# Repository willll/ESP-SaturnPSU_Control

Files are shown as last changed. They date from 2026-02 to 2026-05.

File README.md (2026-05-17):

# ESP8266 D1 HTTP Control

[YouTube Demo: ESP8266 D1 Control Device](https://www.youtube.com/watch?v=zFmUQA3u5PM)

This project runs on an ESP8266 NodeMCU (ESP-12E, CP2102) and exposes a web page plus a REST API to control the D1 pin (GPIO5).

**Vibe coded project for learning purpose only.**

## Hardware Features
- **D1 (GPIO5):** Relay control output (active HIGH)
- **D2 (GPIO4):** Physical NO push button for manual D1 toggle (debounced, respects latch period)
- **Optional:** 10kΩ pull-up resistor for D2 (use only if internal pull-up is insufficient)
- **Relay:** Omron G6B-1114P-US or compatible
- **See:** `hw/BOM_ESP8266_Relay_Control.txt` for full parts list

## Requirements
- PlatformIO (recommended)
- ESP8266 NodeMCU (ESP-12E)
- Python 3.8+ with pip

## Install PlatformIO CLI (Linux)

### Option A: pipx (isolated install, recommended)
1) Install pipx

```bash
python3 -m pip install --user pipx
```

2) Ensure your shell can find pipx

```bash
python3 -m pipx ensurepath
```

3) Install PlatformIO

```bash
pipx install platformio
```

4) Open a new terminal and verify

```bash
pio --version
```

### Option B: pip (user install)
If you prefer not to use pipx:

```bash
python3 -m pip install --user platformio
```

Then verify:

```bash
pio --version
```

### Option C: system packages
Some distros ship a PlatformIO package (may be older). If you use it, ensure `pio --version` shows a recent release.

## USB serial permissions (Linux)
If upload or monitor fails with permission errors, add your user to the serial group and re-login:

```bash
sudo usermod -a -G dialout "$USER"
```

After logging out and back in, confirm access:

```bash
groups
```

Typical device nodes for CP2102 are `/dev/ttyUSB0` or `/dev/ttyUSB1`.

## Regenerate venv and build tools
This project includes a small bootstrap script and `requirements.txt` to recreate the local Python virtual environment and prefetch PlatformIO build tools.

Files:
- `requirements.txt`: Python dependencies for the local venv (includes PlatformIO CLI)
- `scripts/bootstrap.sh`: Creates `.venv`, installs dependencies, and downloads PlatformIO packages

Clean start (optional):

```bash
rm -rf .venv .pio
```

If you also want to wipe globally cached PlatformIO packages (not required):

```bash
rm -rf ~/.platformio
```

Run the bootstrap script:

```bash
chmod +x scripts/bootstrap.sh
./scripts/bootstrap.sh
```

After bootstrap, build as usual:

```bash
./.venv/bin/pio run
```

## WiFi configuration
WiFi credentials are loaded from an unencrypted JSON file on LittleFS.

1. Copy data/wifi_replace_me.json to data/wifi.json
2. Edit data/wifi.json with your credentials
3. Upload the filesystem (see below)

### JSON schema
- `ssid` (string, required): WiFi network name
- `password` (string, required): WiFi password (can be empty for open networks)
- `hostname` (string, optional): Device hostname shown by the router
- `connect_timeout_ms` (number, optional): Max time to wait for WiFi connect; default is 20000
- `notes` (array of strings, optional): Any extra notes; ignored by firmware

Example (wifi_replace_me.json):

```json
{
	"ssid": "your-ssid",
	"password": "your-password",
	"hostname": "esp8266-d1",
	"connect_timeout_ms": 20000,
	"notes": [
		"Replace ssid/password with your network",
		"Extra fields are ignored by the firmware"
	]
}
```

Upload the filesystem before flashing the firmware:

```bash
pio run -t uploadfs
```

## mDNS (Multicast DNS) Support

The device automatically registers on your local network using mDNS, making it accessible via a friendly hostname instead of IP address.

### How to Access

**Web UI:**
```
http://<hostname>.local
```

**REST API:**
```
http://<hostname>.local/api/v1/status
```

**Example:** If your wifi.json has `"hostname": "saturnpsu"`, access it at:
```
http://saturnpsu.local
```

### Test mDNS Connectivity

From any device on the same network, ping the device to verify mDNS registration:

```bash
ping saturnpsu.local
```

**Expected output:**
```
64 bytes from 192.168.1.106: seq=0 ttl=255 time=2.230 ms
```

### mDNS Requirements

- Device and client must be on the **same WiFi network**
- Client device needs **mDNS support** (built-in on macOS, Linux, Windows 10+)
- Hostname must be set in `wifi.json` (see WiFi configuration section above)
- If hostname is empty, mDNS responder is disabled

### Hostname Configuration

Edit `data/wifi.json`:

```json
{
  "hostname": "saturnpsu"
}
```

After changing the hostname, re-upload the filesystem:

```bash
pio run -t uploadfs
```

Reboot the device or power cycle to apply.

## Build and upload

```bash
pio run -t upload
```

Open serial monitor at 74880 to see the device IP and boot logs:

```bash
pio device monitor -b 74880
```
If you are using VS Code tasks, run:
- PlatformIO: Monitor

## Web UI Features

Visit the device IP in a browser to open the control page. The web UI provides:

- **ON/OFF/TOGGLE Buttons:** Instantly control the D1 pin state. Button color reflects the current state (green for ON, red for OFF). Buttons are disabled while the latch is active or if the action is not allowed.
- **Latch Period Input:** Set the latch period (in seconds) to prevent rapid toggling. The input is for user entry only and is not auto-refreshed from device status. Allowed range: 1–3600 seconds.
- **Status Display:** Shows the current D1 state and latch period, updates in real time (every 200ms).
- **Debug Log:** Scrollable area below the controls displays recent debug messages, actions, and API errors. Auto-scrolls as new messages arrive.
- **No Refresh Button:** The UI auto-updates status and disables the Refresh button (removed in latest version).

### Example UI

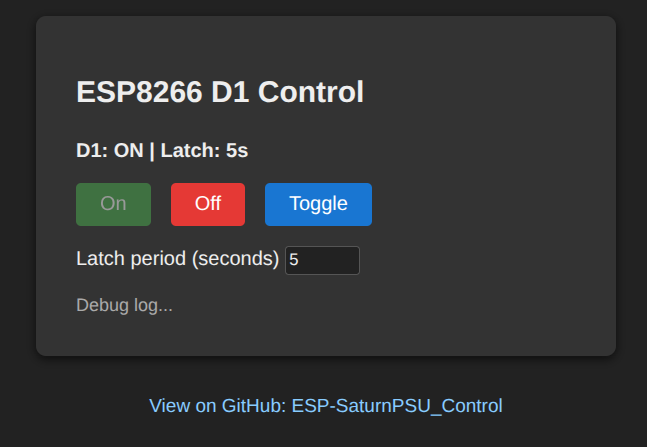
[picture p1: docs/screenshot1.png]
Web UI Screenshot 1

*Main control panel with ON/OFF/TOGGLE, latch input, and debug log.*

> **Tip:** If you see 'Status: ERROR' or debug messages about API failures, check your device connection and network.

## Physical Push Button (D2)

- **D2 (GPIO4):** Connect a normally open (NO) push button between D2 and GND.
- **Behavior:** Pressing the button toggles D1, subject to the latch period (cannot toggle if latch is active). Input is debounced in firmware.
- **Optional:** Add a 10kΩ pull-up resistor if needed (firmware uses INPUT_PULLUP).

## REST API

### REST API Endpoints

| Method | Path | Description | Status | Response |
|---|---|---|---|---|
| GET | / | Web UI (HTML page) | 200 | (HTML) |
| GET | /api/v1/status | Get current relay status and latch info | 200 | See example below |
| POST | /api/v1/on | Set D1 HIGH (ON), starts latch timer if set | 200/423 | `{ "relay_status": "ON", ... }` |
| POST | /api/v1/off | Set D1 LOW (OFF), starts latch timer if set | 200/423 | `{ "relay_status": "OFF", ... }` |
| POST | /api/v1/toggle | Toggle D1 state, starts latch timer if set | 200/423 | `{ "relay_status": "ON\|OFF", ... }` |
| GET | /api/v1/latch  | Get current latch period (seconds) | 200 | `{ "latch": 5 }` |
| POST | /api/v1/latch  | Set latch period (1-3600 seconds, constraints enforced) | 200/400 | `{ "latch": 10 }` |
| GET | /menu | Plain-text status menu (for legacy/CLI use) | 200 | (text) |
| POST | /api/v1/reset  | Clear latch, set D1 LOW (test setup/reset) | 200 | `{ "reset": true }` |
| GET | /openapi.yaml  | OpenAPI 3.0 specification of this API | 200 | (YAML) |

### Status Endpoint Response Format

```json
{
  "relay_status": "ON",
  "latch": 5,
  "latch_timer_active": false,
  "latch_timer_expiry": 0,
  "millis": 1234567
}
```

| Field | Type | Description |
|---|---|---|
| `relay_status` | string | Current relay state: `"ON"` or `"OFF"` |
| `latch` | number | Latch period in seconds (1–3600, or clamped) |
| `latch_timer_active` | boolean | True if latch is currently active and preventing changes |
| `latch_timer_expiry` | number | Milliseconds when latch expires (0 if not active) |
| `millis` | number | Device uptime in milliseconds (for sync reference) |

### HTTP Status Codes

| Code | Meaning | Example |
|---|---|---|
| **200** | Success | Any control or status request succeeded |
| **400** | Bad Request | Invalid JSON in POST body or missing required fields |
| **423** | Locked | Latch is active; state change blocked until latch expires |
| **404** | Not Found | Endpoint doesn't exist |
| **500** | Server Error | Firmware error (rare) |

### Usage Examples

#### Get Current Status
```bash
curl http://saturnpsu.local/api/v1/status
```

**Response:**
```json
{
  "relay_status": "OFF",
  "latch": 5,
  "latch_timer_active": false,
  "latch_timer_expiry": 0,
  "millis": 42325
}
```

#### Turn Relay ON
```bash
curl -X POST http://saturnpsu.local/api/v1/on
```

**Response (200):**
```json
{
  "relay_status": "ON",
  "latch": 5,
  "latch_timer_active": true,
  "latch_timer_expiry": 47325,
  "millis": 42325
}
```

**Response if latch active (423):**
```json
{
  "error": "Latch active"
}
```

#### Set Latch Period
```bash
curl -X POST http://saturnpsu.local/api/v1/latch \
  -H "Content-Type: application/json" \
  -d '{"latch": 10}'
```

**Response (200):**
```json
{
  "latch": 10
}
```

**Invalid constraints (auto-clamped to 1-3600):**
```bash
# Request: latch = 0 (below minimum)
curl -X POST http://saturnpsu.local/api/v1/latch \
  -H "Content-Type: application/json" \
  -d '{"latch": 0}'
# Response: {"latch": 1}  (clamped to min)

# Request: latch = 9999 (above maximum)
curl -X POST http://saturnpsu.local/api/v1/latch \
  -H "Content-Type: application/json" \
  -d '{"latch": 9999}'
# Response: {"latch": 3600}  (clamped to max)
```

#### Toggle Relay
```bash
curl -X POST http://saturnpsu.local/api/v1/toggle
```

#### Get Latch Period
```bash
curl http://saturnpsu.local/api/v1/latch
```

**Response:**
```json
{
  "latch": 5
}
```

#### Reset (Clear latch, set D1 LOW)
```bash
curl -X POST http://saturnpsu.local/api/v1/reset
```

**Response:**
```json
{
  "reset": true
}
```

### API Behavior Notes

- **Latch Constraints:** Latch period is automatically clamped to 1–3600 seconds. Values of 0 or below are set to 1; values above 3600 are set to 3600.
- **Latch Behavior:** When a control endpoint (on/off/toggle) executes successfully, a latch timer starts. Any subsequent control requests return **423 Locked** until the timer expires.
- **No Auto-Revert:** After the latch expires, the relay **remains in its set state** (does not auto-revert).
- **Idempotent:** All endpoints are safe to call repeatedly; duplicate requests are harmless.
- **mDNS Support:** Endpoints are accessible via `http://<hostname>.local/api/v1/...` on any client on the same network.

### OpenAPI Specification

Full OpenAPI 3.0 specification available at:
```
GET /openapi.yaml
```

Serve in [SwaggerUI](https://swagger.io/tools/swagger-ui/) or [ReDoc](https://redoc.ly/) for interactive exploration.

#### Details

- **/api/v1/on, /api/v1/off, /api/v1/toggle:** All return the new D1 state as JSON. If the latch is active, state changes are rejected with `{ "error": "Latch active" }` and HTTP 423.
- **/api/v1/latch:** GET returns current latch period; POST sets a new period (range: 1–3600 seconds). Returns new value as JSON. Setting to 0 disables the latch.
- **/api/v1/reset:** For test setup. Immediately disables latch and sets D1 LOW. Always returns `{ "reset": true }`.
- **/api/v1/status:** Returns current D1 state and latch timer (if active).
- **/menu:** Returns a plain-text status summary for CLI/legacy use.

##### Example: /api/v1/status
```json
{"relay_status":"ON", "latch":0}
```

##### Example: /api/v1/latch (POST)
Request:
```json
{"latch": 10}
```
Response:
```json
{"latch": 10}
```
*Note: Latch period must be between 1 and 3600 seconds. 0 disables latch. See SRS for details.*

##### Example: /api/v1/reset
Request:
```bash
curl -X POST http://<device-ip>/api/v1/reset
```
Response:
```json
{"reset":true}
```

## Automated Testing

This project includes automated and manual test suites for firmware, REST API, web UI, and hardware features:

- **Robot Framework API tests** (recommended, runs in Docker):
	- Location: `scripts/test_api.robot`
	- Run with Docker:
		```bash
		docker build -t esp8266-robot-tests .
		docker run --rm -e DEVICE_IP=192.168.1.107 esp8266-robot-tests
		```
		(Replace the IP as needed.)
	- See `scripts/robot_test_README.md` for details.

- **Python API test script** (optional):
	- Location: `scripts/test_api.py`
	- Run with:
		```bash
		python3 scripts/test_api.py 192.168.1.107
		```

- **Manual Hardware/UI Tests:**
	- See `docs/test-campaign.md` for a full checklist, including:
		- D2 push button toggles D1, respects latch period, and is debounced
		- UI disables ON/OFF/TOGGLE during latch
		- Latch input is input-only (not auto-refreshed)
		- No Refresh button (UI auto-updates)
		- All REST API and UI features

Test results are shown in the terminal or browser. The Robot Framework suite covers all REST API endpoints and device logic.

## Test Campaign

See `docs/test-campaign.md` for a full manual and automated test checklist covering:
- Firmware and REST API
- Web UI (including D2 push button and latch logic)
- Hardware wiring and deployment
- Documentation completeness

## Hardware Images

### Device Front View 1
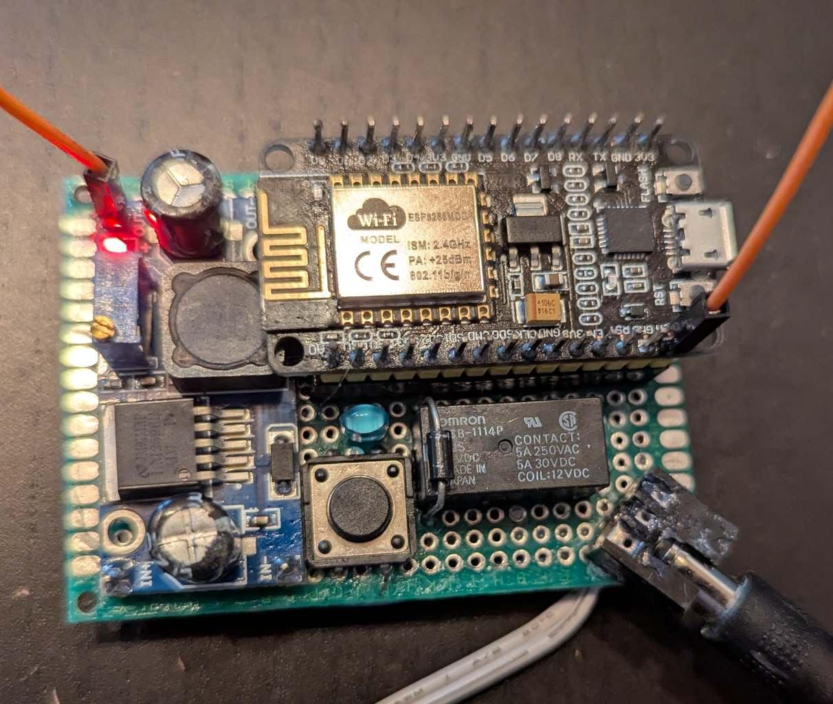
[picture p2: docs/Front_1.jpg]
Device Front 1


### Device Front View 2
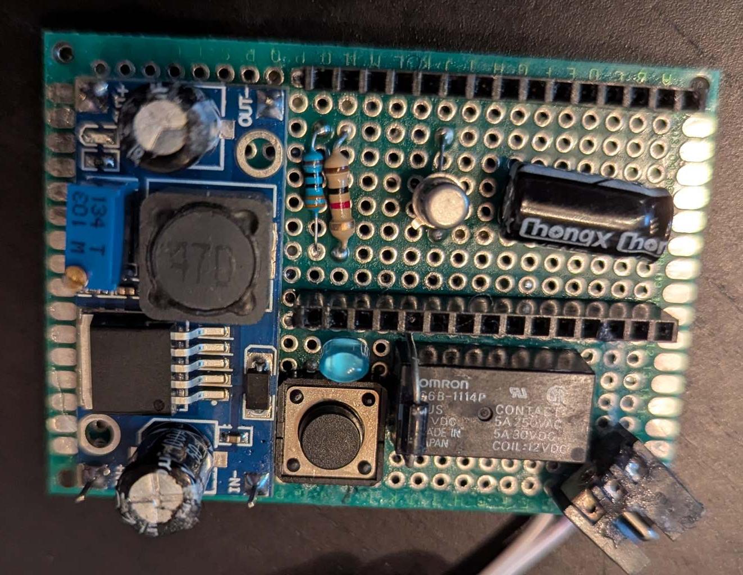
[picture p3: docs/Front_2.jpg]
Device Front 2


## Notes
- D1 corresponds to GPIO5 (relay control output)
- D2 corresponds to GPIO4 (NO push button input)
- The control output is active HIGH by default
- Latch period prevents rapid toggling; minimum 1s, maximum 3600s
- D2 input is debounced and respects latch lockout
- UI disables ON/OFF/TOGGLE during latch; latch input is not auto-refreshed
- See SRS and test campaign for full requirements

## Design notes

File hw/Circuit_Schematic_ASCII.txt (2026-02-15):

================================================================================
        ESP8266 NodeMCU to Omron G6B-1114P-US Relay Control Circuit
                         CIRCUIT SCHEMATIC DIAGRAM
================================================================================

                                    +12V DC POWER SUPPLY
                                        │
                                        │ +12V
                                        │
                   ┌────────────────────┴────────────────────┐
                   │                    │                     │
                   │                    │                   ──┴──  Cathode (−)
                   │                    │                   ╱   ╲  (Stripe)
                   │                    │                  │  D1 │ 1N4007
                   │                    │                   ╲   ╱  Flyback
                   │                    │                   ──┬──  Diode
                   │                    │                     │ Anode (+)
                   │                    │                     │
                   │             ┌──────┴──────┐              │
                   │             │             │              │
                   │             │   RELAY K1  │              │
                   │             │  G6B-1114P  │              │
                   │             │   -US 12V   │              │
                   │             │             │              │
                   │         (1) │●  COIL  ●│ (2)            │
                   │    Coil +   │             │  Coil −      │
                   └─────────────┤   ┌───┐     ├──────────────┘
                                 │   │ ~ │     │
                                 │   │ ~ │     │
                                 │   │ ~ │     │
                                 │   └───┘     │
                                 │             │
                                 │             │
                                 │ (3)     (4) │
                                 │  ●       ●  │
                                 └──┬───────┬──┘
                                    │       │
                                   COM      NO
                                    │       │
                                    │       │
                               (To Load Switching)

                   ┌─────────────────────────────────────────┐
                   │                                         │
                   │        ESP8266 NodeMCU                  │
                   │        ESP-12E CP2102                   │
                   │                                         │
                   │  ┌──────────────────────────┐           │
                   │  │                          │           │
    ┌──────────┐   │  │      ESP8266-12E         │           │
    │ USB 5V   ├───┤  │      WiFi Module         │           │
    │ Power    │   │  │                          │           │
    └──────────┘   │  └──────────────────────────┘           │
                   │                                         │
                   │                                         │
                   │  D1 (GPIO5) ●───────────┐               │
                   │                         │               │
                   │                         │               │
                   │  GND         ●──────────┼───────┐       │
                   │                         │       │       │
                   └─────────────────────────┼───────┼───────┘
                                             │       │
                                             │       │
                      3.3V Signal            │       │
                      (Control)              │       │
                                             │       │
                                         ┌───┴───┐   │
                                         │       │   │
                                         │  R1   │   │
                                         │ 1kΩ   │   │
                                         │       │   │
                                         └───┬───┘   │
                                             │       │
                                             │ Base  │
                                             ▼       │
                                           ┌─┴─┐     │
                                           │╱ ╲│     │
                                      C ───┤   ├     │  Q1: 2N2222
                                           │╲ ╱│     │  NPN Transistor
                                           └─┬─┘     │
                                             │       │
                                             │ Emitter
                                             ▼       │
                                             │       │
                                          ═══╧═══════╧═══  Common GND
                                            GND
                                             │
                                             │
                                          12V DC (−)

================================================================================
CONNECTION TABLE
================================================================================

FROM                    TO                      COMPONENT/WIRE
-------------------------------------------------------------------------------
12V Supply (+)    →     Relay Pin 1             Red Wire
12V Supply (+)    →     Diode D1 Cathode        Red Wire
12V Supply (−)    →     Common GND              Black Wire

Relay Pin 1       →     Relay Coil (+)          Internal
Relay Pin 2       →     Relay Coil (−)          Internal
Relay Pin 2       →     Transistor Q1 Collector Orange Wire
Relay Pin 2       →     Diode D1 Anode          Orange Wire

Transistor Q1:
  - Collector     →     Relay Pin 2             Orange Wire
  - Base          →     Resistor R1 Pin 2       Orange Wire
  - Emitter       →     Common GND              Black Wire

Resistor R1:
  - Pin 1         →     ESP8266 D1 (GPIO5)      Orange Wire
  - Pin 2         →     Transistor Q1 Base      Orange Wire

Diode D1:
  - Cathode (−)   →     +12V / Relay Pin 1      Red Wire
  - Anode (+)     →     Relay Pin 2 / Collector Orange Wire

ESP8266 NodeMCU:
  - D1 (GPIO5)    →     Resistor R1 Pin 1       Orange Wire
  - GND           →     Common GND              Black Wire
  - USB           →     5V Power Supply         USB Cable

Relay Contacts:
  - Pin 3 (COM)   →     Load Common             User Wire
  - Pin 4 (NO)    →     Load Switched Side      User Wire

================================================================================
SIGNAL FLOW
================================================================================

CONTROL SIGNAL PATH:
ESP8266 GPIO5 (3.3V) → R1 (1kΩ) → Q1 Base → Q1 Emitter → GND
Current: ~2.6mA

POWER SWITCHING PATH (when GPIO5 = HIGH):
+12V → Relay Coil Pin 1 → Relay Coil → Relay Coil Pin 2 → Q1 Collector → 
Q1 Emitter → GND
Current: ~30mA

PROTECTION PATH:
When relay de-energizes, flyback voltage: 
Relay Coil → D1 Anode → D1 Cathode → +12V (dissipates energy safely)

================================================================================
VOLTAGE AND CURRENT SPECIFICATIONS
================================================================================

Node                Voltage (V)     Current (mA)    Notes
-------------------------------------------------------------------------------
+12V Supply         12.0            30-50          Power for relay only
ESP8266 GPIO5       3.3             2.6            Control signal
Transistor Base     0.7             2.6            Forward biased
Transistor Emitter  0               32.6           To ground
Relay Coil +        12.0            30             When energized
Relay Coil −        0.2-0.5         30             VCE(sat) voltage
Common GND          0               32.6           Reference point

================================================================================
COMPONENT STRESS ANALYSIS
================================================================================

Component       Parameter           Operating   Maximum   Margin    Status
-------------------------------------------------------------------------------
Q1 (2N2222)    Collector Current     30mA       600mA     20x       ✓ SAFE
Q1 (2N2222)    Collector-Emitter V   12V        40V       3.3x      ✓ SAFE
Q1 (2N2222)    Base Current          2.6mA      -         -         ✓ SAFE
Q1 (2N2222)    Power Dissipation     ~10mW      500mW     50x       ✓ SAFE

R1 (1kΩ)       Power Dissipation     6.8mW      250mW     37x       ✓ SAFE
R1 (1kΩ)       Voltage               2.6V       -         -         ✓ SAFE

D1 (1N4007)    Forward Current       30mA       1A        33x       ✓ SAFE
D1 (1N4007)    Reverse Voltage       12V        1000V     83x       ✓ SAFE

K1 Relay       Coil Voltage          12V        13.2V max 1.1x      ✓ SAFE
K1 Relay       Coil Current          30mA       -         -         ✓ SAFE

ESP8266 GPIO   Output Current        2.6mA      12mA max  4.6x      ✓ SAFE

================================================================================
OPERATING MODES
================================================================================

MODE 1: RELAY OFF (GPIO5 = LOW or 0V)
--------------------------------------
- Transistor Q1 is OFF (not conducting)
- No current flows through relay coil
- Relay contacts: Pin 3 (COM) is OPEN (not connected to Pin 4)
- Load is OFF
- System power: ~80mA (ESP8266 only)

MODE 2: RELAY ON (GPIO5 = HIGH or 3.3V)
----------------------------------------
- Transistor Q1 is ON (saturated)
- Current flows: 12V → Relay Coil → Q1 → GND (~30mA)
- Relay contacts: Pin 3 (COM) is CLOSED to Pin 4 (NO)
- Load is ON (switched)
- System power: ~110mA (ESP8266 + relay)

MODE 3: RELAY SWITCHING OFF (GPIO5 transitions HIGH → LOW)
-----------------------------------------------------------
- Transistor Q1 turns OFF
- Relay coil collapses, generating back-EMF (flyback voltage)
- Diode D1 conducts, providing path for inductive current
- Energy dissipates through D1 and coil resistance
- Duration: ~5-10ms
- Without D1: Voltage spike could exceed 400V and destroy Q1!

================================================================================
DESIGN CALCULATIONS
================================================================================

BASE RESISTOR CALCULATION (R1):
--------------------------------
VCC (ESP8266) = 3.3V
VBE (Q1) = 0.7V
IB (desired) = 2-3mA (for IC = 30mA with hFE = 20, worst case)

R1 = (VCC - VBE) / IB
R1 = (3.3V - 0.7V) / 0.0026A
R1 = 2.6V / 0.0026A
R1 = 1000Ω = 1kΩ ✓

Actual IB = 2.6mA
With hFE = 100 (typical), IC(max) = 260mA (adequate for 30mA relay)

TRANSISTOR SATURATION CHECK:
-----------------------------
IC (relay) = V / R = 12V / 400Ω = 30mA
IB (actual) = 2.6mA
hFE (forced) = IC / IB = 30mA / 2.6mA = 11.5

Since forced hFE << typical hFE, transistor is fully saturated ✓
VCE(sat) ≈ 0.2-0.3V (collector voltage close to ground)

DIODE SELECTION:
----------------
Peak flyback voltage (without diode) = L × (dI/dt)
Estimated: 200-400V for typical relay

1N4007 specs:
- Reverse voltage: 1000V > 400V ✓
- Forward current: 1A > 30mA ✓
- Recovery time: 30µs (adequate for relay switching)

Selection: 1N4007 is appropriate and provides safety margin

POWER SUPPLY SIZING:
--------------------
Relay coil power = V × I = 12V × 30mA = 360mW
Safety factor = 2× (for inrush and reliability)
Minimum supply = 360mW × 2 = 720mW

Recommended: 12V @ 500mA (6W) provides adequate margin ✓

================================================================================
TROUBLESHOOTING GUIDE
================================================================================

PROBLEM: Relay doesn't click when GPIO5 goes HIGH
POSSIBLE CAUSES:
  1. No 12V supply connected → Check power supply
  2. Common ground not connected → Connect ESP8266 GND to 12V GND
  3. Wrong GPIO pin → Verify using D1 (GPIO5)
  4. Transistor damaged or wrong pinout → Check with multimeter
  5. Diode reversed → Cathode should be at +12V

PROBLEM: Relay clicks but contacts don't switch
POSSIBLE CAUSES:
  1. Wrong relay pins used for load → Use Pin 3 (COM) and Pin 4 (NO)
  2. Load current exceeds relay rating → Check load current vs 5A rating
  3. Relay contacts welded → Replace relay

PROBLEM: Transistor gets hot
POSSIBLE CAUSES:
  1. Transistor not saturating → Check base resistor value (1kΩ)
  2. Excessive collector current → Measure relay coil current
  3. Wrong transistor → Verify 2N2222 or equivalent

PROBLEM: ESP8266 resets when relay switches
POSSIBLE CAUSES:
  1. Power supply noise → Add 100µF capacitor across 12V supply
  2. Ground loop → Ensure single-point ground connection
  3. ESP8266 power supply inadequate → Use 1A USB supply

PROBLEM: Relay stays on permanently
POSSIBLE CAUSES:
  1. Transistor shorted → Replace transistor
  2. GPIO pin stuck HIGH → Check ESP8266 code
  3. Base resistor open → Check R1 connection

================================================================================
CIRCUIT ENHANCEMENTS (Optional)
================================================================================

1. LED INDICATOR
   Add LED + 470Ω resistor in series with relay coil to indicate state

2. MANUAL OVERRIDE
   Add push button in parallel with transistor C-E for manual testing

3. SNUBBER CIRCUIT
   Add RC snubber (0.1µF + 100Ω) across relay contacts for AC loads

4. MULTIPLE RELAYS
   Duplicate Q1/R1/D1/K1 circuit for each additional relay
   Use different GPIO pins (D2, D3, etc.)

5. OPTOCOUPLER ISOLATION
   Add 4N35 optocoupler between ESP8266 and transistor for galvanic isolation

6. POWER SUPPLY INTEGRATION
   Use LM7805 or buck converter to power ESP8266 from 12V supply

================================================================================
PCB LAYOUT RECOMMENDATIONS
================================================================================

1. Keep high-current paths (12V and relay) short and wide
2. Place flyback diode physically close to relay coil
3. Use ground plane for common GND
4. Separate analog and digital grounds if using ADC
5. Add mounting holes for relay and ESP8266
6. Include test points for troubleshooting
7. Label all connections on silkscreen
8. Use terminal blocks for external connections

================================================================================
END OF SCHEMATIC DIAGRAM
================================================================================

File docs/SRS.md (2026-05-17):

- The ON button shall be disabled when D1 is ON, and enabled otherwise.
- The OFF button shall be disabled when D1 is OFF, and enabled otherwise.
## Latch Functionality Requirement

- The latch period is a lockout interval that prevents frequent state changes. When a state change (ON, OFF, TOGGLE) occurs, further changes are blocked for the latch period. After the latch period expires, the relay state remains as set; it does not auto-revert. The latch period can be disabled by setting it to 0 (no lockout). The minimum allowed value for the latch (if enabled) is 1 second. Any attempt to set the latch to a negative value or above the maximum must be rejected.
# Software Requirements Specification (SRS)

## Project: ESP-SaturnPSU_Control

### 1. Introduction
#### 1.1 Purpose
This document specifies the requirements for the ESP-SaturnPSU_Control project, which provides firmware and a web-based user interface for controlling a relay (D1) on an ESP8266-based power supply unit, including REST API access, web UI, and automation support.

#### 1.2 Scope
- Control and monitor the D1 relay via web UI and REST API
- Configure latch timing for relay
- Provide feedback and debug information to the user
- Support automated build, upload, and test workflows

#### 1.3 Definitions
- **D1**: The relay control pin on the ESP8266
- **Latch**: The period (in seconds) during which the D1 status cannot be changed after activation
- **REST API**: HTTP endpoints for remote control
- **Web UI**: Browser-based interface served from the device

### 1.4 Constraints
- The default latch period shall be 5 seconds.
- The minimum latch period shall be 1 second.
- The maximum latch period shall be 3600 seconds (1 hour).
- Latch period values outside this range shall be rejected by the system.
- The system shall initialize with the default latch period on first boot or after a reset.

### 1.5 UI Constraints
- The web UI shall be responsive and usable on both desktop and mobile devices.
- All interactive elements (buttons, inputs) shall be clearly labeled and accessible.
- The ON button shall be green if D1 is 1 (ON), and red otherwise.
- The OFF button shall be red if D1 is 1 (ON), and green otherwise.
- The TOGGLE button shall always be blue.
- When the latch is active, the ON, OFF, and TOGGLE buttons shall be disabled.
- The status refresh interval shall be every 200 milliseconds.
- The debug log shall always be visible and update in real time.
- The latch period input is for input only and shall restrict values to the allowed range (1–3600 seconds). The value is not auto-refreshed from device status.
- The UI shall provide clear feedback for all user actions and errors.
- The UI shall include a link to the project’s GitHub repository in the footer.
- The UI shall not require any external resources at runtime (self-contained).
### 1.6 Network Requirements
- The system shall support mDNS (multicast DNS) to register the device on the local network.
- The device shall register with the hostname specified in `wifi.json`.
- The device shall be accessible via `<hostname>.local` from any client on the same WiFi network.
- If hostname is not set or is empty, the mDNS responder shall be disabled.
### 2. Overall Description
#### 2.1 Product Perspective
- Runs on ESP8266 NodeMCU hardware
- Uses PlatformIO for build and deployment
- Web UI is served from LittleFS
- REST API provides programmatic access

#### 2.2 Product Functions
- Turn D1 ON, OFF, or TOGGLE
- Toggle D1 using D2 push button (NO, debounced, respects latch period)
- Set latch period
- Display current D1 and latch status
- Show debug log in UI
- Visual feedback for D1 state in UI
- Automated build/upload/monitor script

#### 2.3 User Classes
- End User: Controls relay via web UI
- Integrator: Uses REST API for automation
- Developer: Builds, uploads, and tests firmware

#### 2.4 Operating Environment
- ESP8266 NodeMCU
- Modern web browser
- PlatformIO toolchain

### 3. Specific Requirements
#### 3.1 Functional Requirements
- [FR1] The system shall provide a web UI to control D1 (ON/OFF/TOGGLE)
- [FR2] The system shall provide a REST API for D1 control and status
- [FR3] The system shall allow setting the latch period via UI and API
- [FR4] The UI shall display the current D1 state and latch period
- [FR5] The UI shall visually highlight the ON/OFF button matching D1 state
- [FR6] The UI shall show a debug log of recent actions
- [FR7] The UI shall poll the backend for status updates every 200 milliseconds
- [FR8] The system shall provide a link to the GitHub project in the UI footer
- [FR9] The system shall support automated build, upload, and monitor via script
- [FR10] The system shall support toggling D1 via a physical D2 push button, respecting latch period and debouncing input.

#### 3.2 Non-Functional Requirements
- [NFR1] The UI shall be responsive and mobile-friendly
- [NFR2] The system shall handle API errors gracefully and inform the user
- [NFR3] The firmware and UI shall be self-contained and require no external dependencies at runtime
- [NFR4] The system shall be open source and documented
- [NFR5] The system shall support mDNS for network discovery via `<hostname>.local`
- [NFR6] The device shall be accessible without knowing its IPv4 address when on the same network

### 4. External Interface Requirements
#### 4.1 Hardware Interfaces
- ESP8266 NodeMCU with relay on D1

#### 4.2 Software Interfaces
- REST API endpoints: /api/v1/on, /api/v1/off, /api/v1/toggle, /api/v1/status, /api/v1/latch, /api/v1/reset
- Web UI: index.html served from LittleFS

#### 4.3 Communications Interfaces
- HTTP over WiFi

### 5. Other Requirements
- The project repository shall include documentation and automation scripts
- The system shall be validated using automated tests

---
End of SRS

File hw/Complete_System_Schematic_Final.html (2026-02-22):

# Complete ESP8266 Relay Control System - Final Schematic

Single 12V Power Supply | Manual Button | Status LED | WiFi Control Ready

⬇ Download Complete Schematic (SVG)

### 🎉 Complete System Features

- Single 12V Power Supply: Powers everything - no USB needed!
- Efficient Power Conversion: LM2596 buck converter (92% efficient, stays cool)
- Manual Control: Push button for local control (toggle function)
- Visual Feedback: Red LED shows when relay is ON
- WiFi Ready: ESP8266 can control via MQTT, HTTP, or home automation
- Protected Circuit: Flyback diode protects transistor from voltage spikes
- Professional Design: All components properly rated and specified

### 📝 Quick Reference

- Power Input: 12V DC, 500mA minimum (recommended 1A)
- ESP8266 Power: 5V regulated from LM2596
- Relay Control: D1 (GPIO5) controls via 2N2222A transistor
- Button Input: D2 (GPIO4) with internal pull-up
- Status LED: D3 (GPIO0) mirrors relay state
- Load Capacity: 5A @ 250VAC or 5A @ 30VDC

### ⚡ Power Consumption

- ESP8266 Idle: ~80mA @ 5V = 0.4W
- ESP8266 Active (WiFi): ~200mA @ 5V = 1.0W
- Relay Coil: ~30mA @ 12V = 0.36W
- Status LED: ~10mA @ 3.3V = 0.03W
- Total System: ~350mA @ 12V = 4.2W maximum

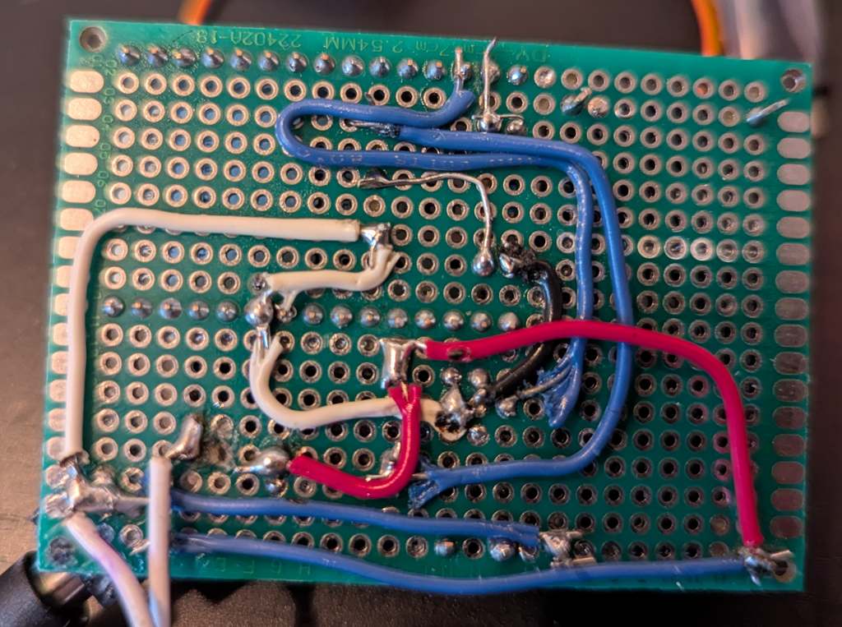
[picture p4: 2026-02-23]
docs/Back.jpg

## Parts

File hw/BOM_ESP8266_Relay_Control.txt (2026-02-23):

===================================================================================
                    BILL OF MATERIALS (BOM)
        ESP8266 NodeMCU to Omron G6B-1114P-US Relay Control Circuit
===================================================================================

Project: ESP8266 12VDC Relay Control
Date: February 15, 2024
Revision: 1.0

===================================================================================
COMPONENT LIST
===================================================================================

Item | Qty | Reference | Value/Part Number      | Description                        | Footprint/Package | Notes
-----|-----|-----------|------------------------|------------------------------------|--------------------|------------------------
  1  |  1  | U1        | ESP8266 NodeMCU        | ESP8266 ESP-12E Development Board  | NodeMCU Board      | CP2102 USB-UART
  2  |  1  | Q1        | 2N2222                 | NPN Transistor 600mA 40V           | TO-92              | Alt: BC547, 2N3904
  3  |  1  | R1        | 1kΩ                    | Resistor 1/4W 5%                   | Axial              | Carbon Film
  4  |  1  | D1        | 1N4007                 | Rectifier Diode 1A 1000V           | DO-41              | Alt: 1N4001-1N4007
  5  |  1  | K1        | G6B-1114P-US           | Relay SPST-NO 12VDC 5A             | PCB Mount 4-pin    | Omron
  6  |  1  | PS1       | 12V DC Supply          | 12V DC Power Supply 500mA min      | Barrel Jack/Term   | Wall Adapter
  7  |  1  | USB1      | USB Cable              | USB Micro-B Cable                  | Cable              | For ESP8266 power
  8  | AR  | WIRE      | 22 AWG Wire            | Stranded hookup wire               | Various colors     | Red, Black, Orange
  9  |  1  | SW1       | NO Push Button           | Momentary Push Button (Normally Open) | Panel/PCB Mount      | For D2 (GPIO4) user input
 10  |  0/1| R2        | 10kΩ (optional)          | Resistor 1/4W 5% (pull-up, if needed) | Axial                | Use if ESP8266 internal pull-up is insufficient

===================================================================================
DETAILED SPECIFICATIONS
===================================================================================

U1 - ESP8266 NodeMCU ESP-12E CP2102
------------------------------------
Manufacturer: Espressif Systems
Microcontroller: ESP8266 ESP-12E
USB-UART Bridge: CP2102
Operating Voltage: 3.3V (5V via USB)
GPIO Pins: 11 usable
Flash Memory: 4MB
Wi-Fi: 802.11 b/g/n
Current Draw: ~80mA (typical), 170mA (peak)
Dimensions: 58mm x 31mm x 13mm

Pinout Used:
  - D1 (GPIO5): Relay control signal output
  - D2 (GPIO4): NO push button input (user control)
  - GND: Ground reference
  - VIN/USB: 5V power input

Power Requirements: 5V 500mA via USB Micro-B

Q1 - 2N2222 NPN Transistor
---------------------------
Type: NPN Bipolar Junction Transistor
Package: TO-92
Collector Current (IC max): 600mA (800mA peak)
Collector-Emitter Voltage (VCEO): 40V
Power Dissipation: 500mW
DC Current Gain (hFE): 100-300 typical
Transition Frequency: 250 MHz

Pin Configuration (TO-92):
  Pin 1: Emitter (E)
  Pin 2: Base (B)
  Pin 3: Collector (C)

NOTE: Pin order may vary by manufacturer. Verify with datasheet!

Alternative Parts:
  - BC547 (100mA, more common in EU)
  - 2N3904 (200mA, common in US)
  - PN2222 (600mA, plastic package)
  - BC337 (800mA, higher current)

R1 - 1kΩ Resistor
------------------
Resistance: 1000Ω (1kΩ)
Power Rating: 1/4W (0.25W)
Tolerance: ±5% (or better)
Type: Carbon Film or Metal Film
Package: Axial Lead
Color Code: Brown-Black-Red-Gold

Purpose: Base current limiting resistor
Calculated Base Current: (3.3V - 0.7V) / 1000Ω ≈ 2.6mA
Actual Power: ~6.8mW (well within rating)

D1 - 1N4007 Rectifier Diode
----------------------------
Type: Rectifier Diode
Forward Current: 1A continuous
Reverse Voltage: 1000V
Forward Voltage Drop: 0.7V @ 1A
Package: DO-41 (Axial)
Recovery Time: 30µs

Polarity Marking: Cathode marked with stripe/band

Purpose: Flyback/Freewheeling diode
Function: Protects transistor from inductive kickback when relay de-energizes
Connection: Cathode to +12V (relay coil +), Anode to collector

Alternative Parts (in order of preference):
  - 1N4007 (1000V) - Recommended
  - 1N4004 (400V) - Adequate
  - 1N4001 (50V) - Minimum acceptable
  - UF4007 (1000V, fast recovery) - Best choice

K1 - Omron G6B-1114P-US Relay
-------------------------------
Manufacturer: Omron Electronics
Part Number: G6B-1114P-US
Type: Single Pole Single Throw - Normally Open (SPST-NO)
Package: PCB Mount, 4-pin through-hole
Mounting: Straight pins, 5mm pitch

Coil Specifications:
  - Nominal Voltage: 12VDC
  - Coil Resistance: 400Ω (typical)
  - Coil Current: 30mA (nominal)
  - Pick-up Voltage: 75% of nominal (9V)
  - Drop-out Voltage: 10% of nominal (1.2V)
  - Operate Time: 10ms max
  - Release Time: 5ms max

Contact Specifications:
  - Configuration: SPST-NO (Form A)
  - Contact Rating: 5A @ 250VAC, 5A @ 30VDC
  - Max Switching Voltage: 250VAC / 110VDC
  - Max Switching Current: 5A
  - Max Switching Power: 1250VA / 150W
  - Contact Resistance: 100mΩ max
  - Mechanical Life: 10,000,000 operations
  - Electrical Life: 100,000 operations (resistive load)

Pin Configuration (4-pin):
  Pin 1: Coil (+) - Connect to +12V
  Pin 2: Coil (-) - Connect to transistor collector
  Pin 3: COM (Common) - Load common terminal
  Pin 4: NO (Normally Open) - Load switched terminal

Dimensions: 29mm x 12.7mm x 15.5mm
Weight: Approximately 5g

Safety: UL, CSA, TÜV approved
Operating Temperature: -40°C to +85°C

PS1 - 12V DC Power Supply
--------------------------
Output Voltage: 12VDC ±5%
Output Current: 500mA minimum (1A recommended)
Input Voltage: 100-240VAC 50/60Hz (universal input)
Connector: 2.1mm or 2.5mm barrel jack, or terminal block
Regulation: <5% typical
Ripple: <100mV p-p typical
Protection: Overcurrent, overvoltage, short-circuit

Power Calculation:
  Relay Coil: 12V × 30mA = 360mW
  Safety Factor: 2x
  Recommended: 12V @ 500mA (6W) minimum

Note: This supply is ONLY for the relay circuit.
ESP8266 is powered separately via USB (5V).

USB1 - USB Cable for ESP8266
-----------------------------
Type: USB Type-A to Micro-B
Length: 1m typical (adjust as needed)
Purpose: Power and programming for ESP8266
Current Rating: 500mA minimum (1A recommended)

WIRE - Hookup Wire
------------------
Type: Stranded copper hookup wire
Gauge: 22 AWG (0.33 mm²)
Insulation: PVC
Voltage Rating: 300V minimum
Temperature Rating: 80°C minimum

Wire Lengths (approximate):
  - Red (+12V): 30cm
  - Black (GND): 50cm
  - Orange (Signal): 20cm

Color Coding:
  - Red: +12V power
  - Black: Ground (GND)
  - Orange/Yellow: Signal (GPIO)

===================================================================================
TOOLS REQUIRED
===================================================================================

- Soldering iron (25-40W)
- Solder (60/40 or lead-free)
- Wire strippers
- Needle-nose pliers
- Multimeter (for testing)
- Breadboard (optional, for prototyping)
- Jumper wires (optional)
- Helping hands or PCB holder

===================================================================================
ASSEMBLY NOTES
===================================================================================

1. VERIFY TRANSISTOR PINOUT
   - TO-92 pinout varies by manufacturer
   - Confirm with datasheet before soldering
   - Flat side typically indicates orientation

2. DIODE POLARITY
   - Cathode (stripe) MUST connect to +12V side
   - Incorrect orientation will damage transistor

3. COMMON GROUND
   - ESP8266 GND and 12V supply GND MUST be connected
   - This is critical for proper operation

4. POWER ISOLATION
   - ESP8266 powered via USB (5V)
   - 12V supply only for relay circuit
   - DO NOT connect 12V to ESP8266 VIN

5. RELAY CONTACT WIRING
   - Pin 3 (COM) and Pin 4 (NO) switch your load
   - Observe load voltage/current ratings
   - Use appropriate wire gauge for load current

6. D2 PUSH BUTTON WIRING
   - Connect one side of SW1 to D2 (GPIO4), other side to GND
   - Enable ESP8266 internal pull-up in firmware (INPUT_PULLUP)
   - If unreliable, add external 10kΩ pull-up resistor from D2 to 3.3V

===================================================================================
TESTING PROCEDURE
===================================================================================

1. Before applying power:
   - Verify all connections with multimeter
   - Check for shorts between power and ground
   - Verify transistor pinout
   - Confirm diode polarity

2. Initial power-up:
   - Connect ESP8266 USB only (no 12V yet)
   - Upload test sketch
   - Verify GPIO output with multimeter

3. Full circuit test:
   - Connect 12V supply
   - Run test program
   - Listen for relay click
   - Measure relay coil voltage
   - Test contact switching with multimeter

4. Load testing:
   - Start with low-current resistive load
   - Gradually increase to rated current
   - Monitor for overheating
   - Verify switching reliability

===================================================================================
ESTIMATED COSTS (USD, 2024)
===================================================================================

ESP8266 NodeMCU:          $4.00 - $8.00
2N2222 Transistor:        $0.10 - $0.30
1kΩ Resistor:            $0.05 - $0.10
1N4007 Diode:            $0.05 - $0.15
Omron G6B-1114P-US:       $3.00 - $6.00
12V Power Supply:         $5.00 - $10.00
USB Cable:                $2.00 - $5.00
Miscellaneous Wire:       $2.00 - $5.00

TOTAL ESTIMATED COST:     $16.20 - $34.55

Note: Prices vary by supplier and quantity
Bulk purchases significantly reduce per-unit cost

===================================================================================
SUPPLIERS
===================================================================================

General Electronics:
  - Digi-Key (www.digikey.com)
  - Mouser (www.mouser.com)
  - Newark/Element14 (www.newark.com)
  - Arrow Electronics (www.arrow.com)

Cost-Effective Options:
  - AliExpress (www.aliexpress.com) - Longer shipping
  - Amazon - Fast shipping, higher prices
  - eBay - Various sellers

Local:
  - Electronics specialty stores
  - Maker spaces
  - University surplus stores

===================================================================================
SAFETY WARNINGS
===================================================================================

⚠️ ELECTRICAL SAFETY
  - Disconnect all power before handling circuit
  - Use proper insulation on exposed connections
  - Observe relay contact voltage/current ratings
  - Do not exceed component specifications

⚠️ RELAY CONTACTS
  - Relay contacts are NOT isolated from coil
  - Switching AC mains requires proper safety measures
  - Use appropriate enclosure for high-voltage loads
  - Follow local electrical codes

⚠️ HEAT MANAGEMENT
  - Transistor may heat up under continuous operation
  - Ensure adequate ventilation
  - Consider heatsink if necessary

===================================================================================
REVISION HISTORY
===================================================================================

Rev 1.0 - 2024-02-15 - Initial release

===================================================================================
END OF BILL OF MATERIALS
===================================================================================

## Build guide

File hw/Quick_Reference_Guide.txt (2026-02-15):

╔══════════════════════════════════════════════════════════════════════════════╗
║                           QUICK REFERENCE GUIDE                              ║
║          ESP8266 NodeMCU to Omron G6B-1114P-US Relay Control Circuit         ║
╚══════════════════════════════════════════════════════════════════════════════╝

┌──────────────────────────────────────────────────────────────────────────────┐
│ COMPONENT PINOUT QUICK REFERENCE                                             │
└──────────────────────────────────────────────────────────────────────────────┘

┌─────────────────────────────────┐
│  2N2222 NPN TRANSISTOR (TO-92)  │
│                                 │
│    Flat Side                    │
│   ┌─────────┐                   │
│   │  E B C  │  (Looking at face)│
│   │  │ │ │  │                   │
│   └──┼─┼─┼──┘                   │
│      │ │ │                      │
│      1 2 3                      │
│                                 │
│  Pin 1: Emitter (E) → GND       │
│  Pin 2: Base (B) → R1           │
│  Pin 3: Collector (C) → Relay   │
│                                 │
│  ⚠️  VERIFY WITH YOUR DATASHEET │
│      Pin order varies!          │
└─────────────────────────────────┘

┌─────────────────────────────────┐
│  1N4007 DIODE                   │
│                                 │
│   ┌────────────┐                │
│───┤            ├───             │
│   └────────────┘                │
│        ▲                        │
│        │                        │
│     Cathode                     │
│     (Stripe)                    │
│                                 │
│  Cathode (−) → +12V             │
│  Anode (+)   → Collector        │
└─────────────────────────────────┘

┌─────────────────────────────────┐
│  OMRON G6B-1114P-US RELAY       │
│  (4-Pin Configuration)          │
│                                 │
│    Physical Pins (Bottom View)  │
│     ┌───────────────┐           │
│     │               │           │
│     │  ┌─────────┐  │           │
│     │  │ RELAY   │  │           │
│     │  └─────────┘  │           │
│     │               │           │
│     └───┬─┬───┬─┬───┘           │
│         │ │   │ │               │
│         1 2   3 4               │
│                                 │
│  Pin 1: Coil (+)  → +12V        │
│  Pin 2: Coil (−)  → Collector   │
│  Pin 3: COM       → Load common │
│  Pin 4: NO        → Load switch │
└─────────────────────────────────┘

┌──────────────────────────────────────────────────────────────────────────────┐
│ WIRING COLOR CODE                                                            │
└──────────────────────────────────────────────────────────────────────────────┘

🔴 RED    = +12V Power (to Relay Pin 1 and Diode Cathode)
⚫ BLACK  = Ground (Common GND - MUST connect ESP8266 and 12V supply)
🟠 ORANGE = Signal/Control (ESP8266 D1 → R1 → Transistor Base)
🟡 YELLOW = Collector path (Relay Pin 2 ← Transistor Collector)

┌──────────────────────────────────────────────────────────────────────────────┐
│ CONNECTION CHECKLIST                                                         │
└──────────────────────────────────────────────────────────────────────────────┘

Before Powering Up:

☐ 1. ESP8266 D1 (GPIO5) → 1kΩ Resistor → Transistor BASE
☐ 2. ESP8266 GND → Common Ground Point
☐ 3. Transistor EMITTER → Common Ground Point
☐ 4. Transistor COLLECTOR → Relay Pin 2 (Coil −)
☐ 5. +12V Supply → Relay Pin 1 (Coil +)
☐ 6. +12V Supply → Diode CATHODE (stripe end)
☐ 7. Diode ANODE → Relay Pin 2 / Collector junction
☐ 8. 12V Supply GND → Common Ground Point
☐ 9. Verify transistor pinout with multimeter
☐ 10. Double-check diode polarity (stripe to +12V)

┌──────────────────────────────────────────────────────────────────────────────┐
│ TESTING PROCEDURE                                                            │
└──────────────────────────────────────────────────────────────────────────────┘

Step 1: Visual Inspection
  ☐ All connections secure
  ☐ No shorts between power and ground
  ☐ Diode stripe pointing to +12V
  ☐ Transistor correctly oriented

Step 2: Resistance Check (Power OFF)
  ☐ Measure relay coil: Should read ~400Ω between pins 1 & 2
  ☐ Check for shorts: +12V to GND should be >10kΩ
  ☐ Verify ground continuity: ESP GND to 12V GND = 0Ω

Step 3: Power ESP8266 Only (No 12V yet)
  ☐ Connect USB to ESP8266
  ☐ Upload test code
  ☐ Measure GPIO5: Should toggle between 0V and 3.3V
  ☐ Measure at transistor base: Should see ~0.6-0.7V when GPIO HIGH

Step 4: Full Circuit Test
  ☐ Connect 12V supply
  ☐ Run test program
  ☐ Listen for relay "click"
  ☐ Measure relay coil voltage: Should be ~12V when activated
  ☐ Measure collector voltage: Should be near 0V when ON, 12V when OFF

Step 5: Load Test
  ☐ Connect low-current LED + resistor to relay contacts (test load)
  ☐ Verify switching action
  ☐ Test with actual load (within relay ratings)

┌──────────────────────────────────────────────────────────────────────────────┐
│ SAMPLE ARDUINO CODE                                                          │
└──────────────────────────────────────────────────────────────────────────────┘

// ESP8266 Relay Control - Basic Example
const int RELAY_PIN = D1;  // GPIO5

void setup() {
  pinMode(RELAY_PIN, OUTPUT);
  digitalWrite(RELAY_PIN, LOW);  // Relay OFF
  Serial.begin(115200);
  Serial.println("ESP8266 Relay Control Ready");
}

void loop() {
  // Turn relay ON
  digitalWrite(RELAY_PIN, HIGH);
  Serial.println("Relay ON");
  delay(2000);
  
  // Turn relay OFF
  digitalWrite(RELAY_PIN, LOW);
  Serial.println("Relay OFF");
  delay(2000);
}

// Advanced: Control via WiFi
#include <ESP8266WiFi.h>
#include <ESP8266WebServer.h>

const char* ssid = "YOUR_WIFI_SSID";
const char* password = "YOUR_WIFI_PASSWORD";

ESP8266WebServer server(80);

void setup() {
  pinMode(RELAY_PIN, OUTPUT);
  digitalWrite(RELAY_PIN, LOW);
  
  WiFi.begin(ssid, password);
  while (WiFi.status() != WL_CONNECTED) {
    delay(500);
  }
  
  server.on("/on", []() {
    digitalWrite(RELAY_PIN, HIGH);
    server.send(200, "text/plain", "Relay ON");
  });
  
  server.on("/off", []() {
    digitalWrite(RELAY_PIN, LOW);
    server.send(200, "text/plain", "Relay OFF");
  });
  
  server.begin();
  Serial.println("Server started at: " + WiFi.localIP().toString());
}

void loop() {
  server.handleClient();
}

┌──────────────────────────────────────────────────────────────────────────────┐
│ TROUBLESHOOTING QUICK FIXES                                                  │
└──────────────────────────────────────────────────────────────────────────────┘

Problem: Relay doesn't click
├─ Check: Is 12V supply connected and powered?
├─ Check: Is common ground connected? (MOST COMMON ISSUE)
├─ Measure: Voltage at transistor base when GPIO HIGH (should be ~0.7V)
└─ Measure: Voltage at relay coil Pin 1 (should be 12V)

Problem: Relay clicks but load doesn't switch
├─ Verify: Load connected to Pins 3 (COM) and 4 (NO)?
├─ Check: Load current within 5A rating?
└─ Test: Measure continuity between Pin 3 and 4 when relay activated

Problem: ESP8266 resets when relay switches
├─ Add: 100µF capacitor across 12V supply (near relay)
├─ Check: USB power supply adequate? (Use 1A minimum)
└─ Verify: Ground connections solid and short

Problem: Transistor gets hot
├─ Check: Base resistor is 1kΩ (not higher value)
├─ Measure: Collector current (should be ~30mA)
└─ Verify: Correct transistor (2N2222 or equivalent)

Problem: Diode gets hot
├─ CRITICAL: Check diode polarity immediately!
├─ Stripe (cathode) MUST be at +12V side
└─ If reversed, replace diode before continuing

┌──────────────────────────────────────────────────────────────────────────────┐
│ SAFETY REMINDERS                                                             │
└──────────────────────────────────────────────────────────────────────────────┘

⚠️  NEVER connect 12V to ESP8266 VIN or any GPIO pin
⚠️  ALWAYS connect common ground between ESP8266 and 12V supply
⚠️  VERIFY transistor pinout before soldering (varies by manufacturer)
⚠️  CHECK diode polarity (stripe to +12V)
⚠️  OBSERVE relay contact ratings (5A max)
⚠️  USE proper enclosure for AC mains loads
⚠️  DISCONNECT power before handling circuit

┌──────────────────────────────────────────────────────────────────────────────┐
│ MEASUREMENT REFERENCE VALUES                                                 │
└──────────────────────────────────────────────────────────────────────────────┘

Location                Expected Voltage    Expected Current    Notes
─────────────────────────────────────────────────────────────────────────────
ESP8266 GPIO5 (HIGH)    3.3V               2-3mA output        Control signal
Transistor Base         0.6-0.7V           2.6mA               When ON
Transistor Collector    0.2-0.5V (ON)      30mA                When saturated
                        12V (OFF)          0mA                 When cutoff
Relay Coil Pin 1        12V                30mA                When activated
Relay Coil Pin 2        0.2-0.5V           30mA                When activated
Common Ground           0V (reference)     30-35mA total       When ON

┌──────────────────────────────────────────────────────────────────────────────┐
│ ORDERING INFORMATION                                                         │
└──────────────────────────────────────────────────────────────────────────────┘

Component              Part Number           Quantity    Est. Cost
─────────────────────────────────────────────────────────────────────────────
ESP8266 Board          NodeMCU ESP-12E       1          $4-8
Transistor            2N2222 (TO-92)         1          $0.10-0.30
Resistor              1kΩ 1/4W               1          $0.05-0.10
Diode                 1N4007                 1          $0.05-0.15
Relay                 G6B-1114P-US           1          $3-6
Power Supply          12V 500mA              1          $5-10
USB Cable             Micro-B                1          $2-5
Wire                  22 AWG Stranded        As needed  $2-5
──────────────────────────────────────────────────────────────────────────────
                                        TOTAL: $16-35 USD

Search Terms for Suppliers:
• Digi-Key: "G6B-1114P-US DC12"
• Mouser: "653-G6B-1114P-US"
• AliExpress: "ESP8266 NodeMCU" + "Omron relay 12V" + "2N2222"

┌──────────────────────────────────────────────────────────────────────────────┐
│ DOCUMENTATION FILES INCLUDED                                                 │
└──────────────────────────────────────────────────────────────────────────────┘

1. BOM_ESP8266_Relay_Control.txt
   → Complete Bill of Materials with specifications

2. Circuit_Schematic_ASCII.txt
   → Detailed ASCII schematic with calculations

3. ESP8266_Relay_Circuit.net
   → KiCAD-style netlist

4. ESP8266_Relay_Circuit.cir
   → SPICE simulation netlist

5. Quick_Reference_Guide.txt (this file)
   → Fast reference for building and testing

┌──────────────────────────────────────────────────────────────────────────────┐
│ SUPPORT & RESOURCES                                                          │
└──────────────────────────────────────────────────────────────────────────────┘

ESP8266 Documentation:
• https://arduino-esp8266.readthedocs.io/

Omron Relay Datasheet:
• Search: "Omron G6B-1114P-US datasheet PDF"

Component Datasheets:
• 2N2222: Search "2N2222 datasheet" for your specific package
• 1N4007: Standard rectifier diode specifications

Forums & Communities:
• ESP8266 Community Forum
• Arduino Forum
• Reddit: r/esp8266
• Stack Exchange: Electrical Engineering

╔══════════════════════════════════════════════════════════════════════════════╗
║                        END OF QUICK REFERENCE GUIDE                          ║
║                                                                              ║
║  For detailed information, refer to the complete documentation files         ║
║  Always double-check connections before applying power!                      ║
╚══════════════════════════════════════════════════════════════════════════════╝

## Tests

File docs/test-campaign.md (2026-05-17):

# ESP8266 D1 Control Test Campaign

This document describes the recommended test campaign for the ESP8266 D1 Control project. It covers functional, integration, and UI tests to ensure reliability and usability.

## 1. Firmware/REST API Tests

### 1.1. Power-on and WiFi
- [ ] Device boots and connects to WiFi (check serial monitor for IP and status)
- [ ] Handles missing or invalid wifi.json gracefully (error message on serial)
- [ ] mDNS responder starts successfully after WiFi connection
- [ ] Device registers with hostname from wifi.json (e.g., `saturnpsu.local`)
- [ ] Can ping device at `<hostname>.local` from another device on same network
- [ ] Serial output shows: `mDNS responder started: <hostname>.local`

### 1.2. REST API Endpoints
- [ ] `POST /api/v1/on` sets D1 pin HIGH, returns success (both IP and hostname)
- [ ] `POST /api/v1/off` sets D1 pin LOW, returns success (both IP and hostname)
- [ ] `POST /api/v1/toggle` toggles D1 pin, returns new state (both IP and hostname)
- [ ] `GET /api/v1/status` returns current D1 state as JSON (both IP and hostname)
- [ ] `GET /menu` returns plain-text status
- [ ] All endpoints handle errors (invalid method, malformed request)
- [ ] `POST /api/v1/reset` clears latch and sets D1 LOW for test setup
- [ ] Endpoints are accessible via `http://<hostname>.local` without IP address

### 1.3. Latch Logic
- [ ] Setting ON or OFF with a latch period reverts state after the correct time
- [ ] Latch period input of 0 disables latch
- [ ] Rapid toggling does not break latch logic

## 2. Web UI Tests

### 2.1. UI Elements
- [ ] ON, OFF, TOGGLE buttons are visible and enabled
- [ ] Latch period input is present, accepts numbers, and is input-only (not auto-refreshed)
- [ ] Debug log area is visible, fixed size, and scrolls automatically

### 2.4. D2 Push Button
- [ ] Physical D2 push button toggles D1 state
- [ ] D2 respects latch period (cannot toggle D1 while latch is active)
- [ ] D2 input is debounced (no multiple toggles per press)

### 2.2. UI Behavior
- [ ] Button color reflects D1 state (green for ON, orange for OFF)
- [ ] Status text updates after each action
- [ ] Debug log shows all actions, errors, and API failures
- [ ] Latch period input works as expected
- [ ] UI recovers gracefully from API/network errors

### 2.3. Browser Compatibility
- [ ] UI works in Chrome, Firefox, and Edge (basic test)
- [ ] Mobile browser layout is usable

## 3. Network & Filesystem Deployment
- [ ] All files in data/ are uploaded to LittleFS (index.html, wifi.json)
- [ ] Device serves latest UI after uploadfs
- [ ] Device is accessible via hostname after uploadfs and reboot
- [ ] Changing hostname in wifi.json and re-uploading changes mDNS registration

## 4. Documentation
- [ ] README is up to date and clear
- [ ] Screenshots are present in docs/ (if available)
- [ ] Test campaign is included in docs/

---

> Mark each test as complete after verification. Add notes for any failures or unexpected behavior.

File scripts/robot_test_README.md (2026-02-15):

# Run Robot Framework API tests for ESP8266 D1 Control
# Usage:
#   docker build -t esp8266-robot-tests .
#   docker run --rm -e DEVICE_IP=192.168.1.107 esp8266-robot-tests

# To override the device IP, set the DEVICE_IP environment variable.
# Results will be shown in the container output.

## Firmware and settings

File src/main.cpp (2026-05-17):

/**
 * @file main.cpp
 * @brief ESP8266 D1 Control Firmware
 *
 * Provides REST API and web UI for D1 pin control with latch logic.
 */

#include <Arduino.h>
#include <ESP8266WiFi.h>
#include <ESP8266WebServer.h>
#include <ESP8266mDNS.h>
#include <ArduinoJson.h>
#include <LittleFS.h>


/**
 * @brief Default WiFi transmit power (dBm)
 * Lower values reduce power consumption and range. Typical range: 0–20.5 dBm.
 * Adjust as needed for your environment.
 */
static const uint8_t kWifiTxPowerDbm = 15;

// Test mode: If true, after latch expiry, return HTTP 202 until main loop clears latch.
// Enabled by presence of /test_mode file in LittleFS.
static bool testMode = false;

/**
 * GPIO pin for relay/relay control (D1)
 */
static const uint8_t kD1Pin = D1;
static const uint8_t kD2Pin = D2; // D2 push button (NO)
static bool lastD2State = false; // Track last D2 state

/**
 * HTTP server on port 80
 */
static ESP8266WebServer server(80);

/**
 * Last WiFi error message for diagnostics
 */
static String lastWifiError;

/**
 * Latch period (ms), timer expiry, and last state for auto-revert
 */
static uint32_t latchPeriodMs = 5000; // Default: 5 seconds
static uint32_t latchTimerExpiry = 0;

/**
 * @brief Helper: Returns true if latch timer has expired but main loop has not yet cleared the latch.
 * Used in test mode to signal a race window for robust test automation.
 */
static bool isLatchExpiredButNotCleared() {
  return latchTimerExpiry > 0 && ((int32_t)(millis() - latchTimerExpiry) >= 0);
}

/**
 * @struct WifiConfig
 * @brief WiFi configuration structure
 */
struct WifiConfig {
  String ssid;
  String pass;
  String hostname;
  uint32_t connectTimeoutMs = 20000;
};

// Load WiFi configuration from LittleFS (/wifi.json)
/**
 * @brief Load WiFi configuration from LittleFS (/wifi.json)
 * @param[out] cfg Populated with loaded config if successful
 * @return true if config loaded, false on error
 */
static bool loadWifiConfig(WifiConfig &cfg) {
  if (!LittleFS.begin()) {
    Serial.println("LittleFS mount failed");
    lastWifiError = "LittleFS mount failed";
    return false;
  }
  if (!LittleFS.exists("/wifi.json")) {
    Serial.println("/wifi.json not found (copy wifi_replace_me.json and rename)");
    lastWifiError = "/wifi.json not found";
    return false;
  }
  File file = LittleFS.open("/wifi.json", "r");
  if (!file) {
    Serial.println("Failed to open /wifi.json");
    lastWifiError = "Failed to open /wifi.json";
    return false;
  }
  DynamicJsonDocument doc(384);
  DeserializationError err = deserializeJson(doc, file);
  file.close();
  if (err) {
    Serial.print("Failed to parse /wifi.json: ");
    Serial.println(err.c_str());
    lastWifiError = "Failed to parse /wifi.json";
    return false;
  }
  cfg.ssid = String(doc["ssid"] | "");
  cfg.pass = String(doc["password"] | "");
  cfg.hostname = String(doc["hostname"] | "");
  cfg.connectTimeoutMs = doc["connect_timeout_ms"] | 20000;
  cfg.ssid.trim();
  cfg.pass.trim();
  cfg.hostname.trim();
  if (cfg.ssid.length() == 0) {
    Serial.println("Invalid WiFi config: ssid is empty");
    lastWifiError = "Invalid WiFi config: ssid is empty";
    return false;
  }
  return true;
}

// Convert WiFi status code to human-readable string
/**
 * @brief Convert WiFi status code to human-readable string
 * @param status wl_status_t code
 * @return const char* description
 */
static const char *wifiStatusToString(wl_status_t status) {
  int code = static_cast<int>(status);
  if (code == 3) {
    return "Connected";
  }
  switch (status) {
    case WL_CONNECTED:
      return "Connected";
    case WL_NO_SSID_AVAIL:
      return "SSID not found";
    case WL_CONNECT_FAILED:
      return "Connect failed";
    case WL_WRONG_PASSWORD:
      return "Wrong password";
    case WL_DISCONNECTED:
      return "Disconnected";
    case WL_IDLE_STATUS:
      return "Idle";
    case WL_CONNECTION_LOST:
      return "Connection lost";
    default:
      return "Unknown";
  }
}

// Build status menu text for serial output
/**
 * @brief Build status menu text for serial output
 * @param cfg WiFi config
 * @return String status text
 */
static String buildMenuText(const WifiConfig &cfg) {
  String text;
  text.reserve(256);
  text += "=== ESP8266 Status ===\n";
  text += "SSID: ";
  text += cfg.ssid.length() > 0 ? cfg.ssid : "(not set)";
  text += "\nHostname: ";
  text += cfg.hostname.length() > 0 ? cfg.hostname : "(not set)";
  text += "\nWiFi status: ";
  text += wifiStatusToString(WiFi.status());
  text += " (WL_ code ";
  text += String(static_cast<int>(WiFi.status()));
  text += ")\nIP address: ";
  text += WiFi.localIP().toString();
  if (lastWifiError.length() > 0) {
    text += "\nLast error: ";
    text += lastWifiError;
  }
  text += "\nCommands: m or ? to show this menu\n";
  return text;
}

/**
 * @brief Print status menu to serial
 * @param cfg WiFi config
 */
static void printMenu(const WifiConfig &cfg) {
  Serial.println("\n" + buildMenuText(cfg));
}

// Handle /menu endpoint (plain text status)
/**
 * Handle /menu endpoint (plain text status)
 */
static void handleMenu() {
  WifiConfig cfg;
  loadWifiConfig(cfg);
  server.send(200, "text/plain", buildMenuText(cfg));
}


// Send current D1 state and latch period as JSON
/**
 * @brief Send current D1 state and latch period as JSON
 * @endpoint /api/v1/status (GET)
 */
static void sendJsonStatus() {
  // Compose status JSON with relay status as 'ON' or 'OFF', latch period, and timer info
  const char *relayStatus = digitalRead(kD1Pin) ? "ON" : "OFF";
  bool latchActive = latchTimerExpiry > 0 && ((int32_t)(latchTimerExpiry - millis()) > 0);
  String payload = String("{\"relay_status\":\"") + relayStatus + "\""
    + ",\"latch\":" + latchPeriodMs/1000
    + ",\"latch_timer_active\":" + (latchActive ? "true" : "false")
    + ",\"latch_timer_expiry\":" + latchTimerExpiry
    + ",\"millis\":" + millis() + "}";
  server.send(200, "application/json", payload);
}

// GET returns {"latch": seconds}, POST sets latch period (seconds)
/**
 * Handle /api/v1/latch GET/POST: get or set latch period
 * @endpoint /api/v1/latch (GET, POST)
 */
static void handleLatch() {
  // GET: Return current latch period (seconds)
  if (server.method() == HTTP_GET) {
    String payload = String("{\"latch\":") + (latchPeriodMs/1000) + "}";
    server.send(200, "application/json", payload);
    return;
  }
  // POST: Set new latch period (seconds, clamped 1-3600)
  if (server.method() == HTTP_POST) {
    if (!server.hasArg("plain")) {
      server.send(400, "application/json", "{\"error\":\"Missing body\"}");
      return;
    }
    DynamicJsonDocument doc(64);
    DeserializationError err = deserializeJson(doc, server.arg("plain"));
    if (err) {
      server.send(400, "application/json", "{\"error\":\"Invalid JSON\"}");
      return;
    }
    int seconds = doc["latch"] | 0;
    if (seconds < 1) seconds = 1;
    if (seconds > 3600) seconds = 3600;
    latchPeriodMs = seconds * 1000;
    server.send(200, "application/json", String("{\"latch\":") + seconds + "}");
  }
}

// Serve index.html from LittleFS at root
/**
 * @brief Serve index.html from LittleFS at root
 * @endpoint / (GET)
 */
static void handleIndex() {
  File file = LittleFS.open("/index.html", "r");
  if (!file) {
    server.send(404, "text/plain", "index.html not found");
    return;
  }
  server.streamFile(file, "text/html");
  file.close();
}
  // Serve openapi.yaml from LittleFS at /openapi.yaml
  /**
   * @brief Serve openapi.yaml from LittleFS
   * @endpoint /openapi.yaml (GET)
   */
  static void handleOpenApiSpec() {
    File file = LittleFS.open("/openapi.yaml", "r");
    if (!file) {
      server.send(404, "text/plain", "openapi.yaml not found");
      return;
    }
    server.streamFile(file, "text/plain");
    file.close();
  }




// Handle /api/v1/on: set D1 HIGH, start latch timer
/**
 * @brief Handle /api/v1/on: set D1 HIGH, start latch timer
 * @endpoint /api/v1/on (POST)
 */
static bool isLatchActive() {
  // Returns true if latch timer is active (not expired)
  return latchTimerExpiry > 0 && ((int32_t)(latchTimerExpiry - millis()) > 0);
}

void setD1On() {
  digitalWrite(kD1Pin, HIGH);
  latchTimerExpiry = millis() + latchPeriodMs;
}

void setD1Off() {
  digitalWrite(kD1Pin, LOW);
  latchTimerExpiry = millis() + latchPeriodMs;
}

void toggleD1() {
  int current = digitalRead(kD1Pin);
  if (current == LOW) {
    setD1On();
  } else {
    setD1Off();
  }
}

static void handleOn() {
  Serial.print("[API] POST /api/v1/on at millis=");
  Serial.println(millis());
  // Clear latch if expired (fix race with main loop)
  if (latchTimerExpiry > 0 && millis() > latchTimerExpiry) {
    latchTimerExpiry = 0;
  }
  if (isLatchActive()) {
    server.send(423, "application/json", "{\"error\":\"Latch active\"}");
    return;
  }
  if (testMode && isLatchExpiredButNotCleared()) {
    server.send(202, "application/json", "{\"info\":\"Latch expired, wait for clear\"}");
    return;
  }
  setD1On();
  sendJsonStatus();
}

// Handle /api/v1/off: set D1 LOW, start latch timer
/**
 * @brief Handle /api/v1/off: set D1 LOW, start latch timer
 * @endpoint /api/v1/off (POST)
 */
static void handleOff() {
  Serial.print("[API] POST /api/v1/off at millis=");
  Serial.println(millis());
  // Clear latch if expired (fix race with main loop)
  if (latchTimerExpiry > 0 && millis() > latchTimerExpiry) {
    latchTimerExpiry = 0;
  }
  if (isLatchActive()) {
    server.send(423, "application/json", "{\"error\":\"Latch active\"}");
    return;
  }
  if (testMode && isLatchExpiredButNotCleared()) {
    server.send(202, "application/json", "{\"info\":\"Latch expired, wait for clear\"}");
    return;
  }
  setD1Off();
  sendJsonStatus();
}

// Handle /api/v1/toggle: toggle D1, start latch timer
/**
 * @brief Handle /api/v1/toggle: toggle D1, start latch timer
 * @endpoint /api/v1/toggle (POST)
 */
// Handle /api/v1/toggle: toggle D1, using ON/OFF logic and latch respect
/**
 * @brief Handle /api/v1/toggle: toggle D1, using ON/OFF logic and latch respect
 * @endpoint /api/v1/toggle (POST)
 */
static void handleToggle() {
  Serial.print("[API] POST /api/v1/toggle at millis=");
  Serial.println(millis());
  // Clear latch if expired (fix race with main loop)
  if (latchTimerExpiry > 0 && millis() > latchTimerExpiry) {
    latchTimerExpiry = 0;
  }
  if (isLatchActive()) {
    server.send(423, "application/json", "{\"error\":\"Latch active\"}");
    return;
  }
  if (testMode && isLatchExpiredButNotCleared()) {
    server.send(202, "application/json", "{\"info\":\"Latch expired, wait for clear\"}");
    return;
  }
  // Enable test mode if /test_mode file exists
  if (LittleFS.begin() && LittleFS.exists("/test_mode")) {
    testMode = true;
  }
  toggleD1();
  sendJsonStatus();
}

// Arduino setup: initialize hardware, WiFi, and HTTP server
/**
 * @brief Arduino setup: initialize hardware, WiFi, and HTTP server
 */
void setup() {
  Serial.begin(74880);
  Serial.setDebugOutput(false);
  delay(800);

  pinMode(kD1Pin, OUTPUT);
  digitalWrite(kD1Pin, LOW);
  pinMode(kD2Pin, INPUT_PULLUP); // D2 as input, NO button
  lastD2State = digitalRead(kD2Pin);

  WifiConfig cfg;
  if (!loadWifiConfig(cfg)) {
    Serial.println("WiFi config missing or invalid; add /wifi.json and reboot");
  } else {
    WiFi.mode(WIFI_STA);
    if (cfg.hostname.length() > 0) {
      WiFi.hostname(cfg.hostname);
    }

    WiFi.begin(cfg.ssid.c_str(), cfg.pass.c_str());
    WiFi.setOutputPower(kWifiTxPowerDbm); // Set WiFi TX power (dBm)

    uint32_t start = millis();
    wl_status_t lastStatus = WiFi.status();
    while (WiFi.status() != WL_CONNECTED && millis() - start < cfg.connectTimeoutMs) {
      delay(250);
      wl_status_t status = WiFi.status();
      if (status != lastStatus) {
        Serial.print("\nWiFi status: ");
        Serial.println(wifiStatusToString(status));
        lastStatus = status;
      } else {
        Serial.print(".");
      }
    }

    if (WiFi.status() == WL_CONNECTED) {
      Serial.print("\nConnected, IP: ");
      Serial.println(WiFi.localIP());
      Serial.print("IPv4 Address: ");
      Serial.println(WiFi.localIP());
      
      // Initialize mDNS responder
      if (MDNS.begin(cfg.hostname.c_str())) {
        Serial.print("mDNS responder started: ");
        Serial.print(cfg.hostname);
        Serial.println(".local");
        MDNS.addService("http", "tcp", 80);
      } else {
        Serial.println("mDNS responder failed to start");
      }
      
      lastWifiError = "";
    } else {
      wl_status_t finalStatus = WiFi.status();
      Serial.print("\nWiFi connect failed: ");
      Serial.print(wifiStatusToString(finalStatus));
      Serial.print(" (WL_ code ");
      Serial.print(static_cast<int>(finalStatus));
      Serial.println(")");
      Serial.println("Check SSID, password, and signal strength");
      lastWifiError = String("WiFi connect failed: ") + wifiStatusToString(finalStatus);
    }
  }

  printMenu(cfg);

  server.on("/", HTTP_GET, handleIndex);
  server.on("/api/v1/status", HTTP_GET, sendJsonStatus);
  server.on("/api/v1/on", HTTP_POST, handleOn);
  server.on("/api/v1/off", HTTP_POST, handleOff);
  server.on("/api/v1/toggle", HTTP_POST, handleToggle);

  server.on("/menu", HTTP_GET, handleMenu);
  server.on("/api/v1/latch", HTTP_GET, handleLatch);
  server.on("/api/v1/latch", HTTP_POST, handleLatch);
    // Serve OpenAPI spec at /openapi.yaml
    server.on("/openapi.yaml", HTTP_GET, handleOpenApiSpec);

  // Expose /api/v1/reset endpoint for test setup (clears latch and sets D1 LOW)
  server.on("/api/v1/reset", HTTP_POST, []() {
    // POST /api/v1/reset: Clear latch and set D1 LOW (for test setup)
    latchTimerExpiry = 0;
    digitalWrite(kD1Pin, LOW);
    server.send(200, "application/json", "{\"reset\":true}");
  });

  server.begin();
  Serial.println("HTTP server started");
}

// Arduino main loop: handle HTTP requests and latch timer
/**
 * @brief Arduino main loop: handle HTTP requests and latch timer
 */
void loop() {
    // Removed unused variable lastLoopPrint
    // ...existing code...
  server.handleClient();
  MDNS.update();

  // D2 push button logic: toggle D1 on press, respect latch
  bool d2State = digitalRead(kD2Pin);
  // Button pressed: LOW (NO, pullup)
  if (!d2State && lastD2State) { // Detect falling edge
    Serial.print("[D2] Button pressed at millis=");
    Serial.println(millis());
    // Only toggle if latch is not active
    if (!(latchTimerExpiry > 0 && ((int32_t)(latchTimerExpiry - millis()) > 0))) {
      Serial.println("[D2] Toggling D1");
      toggleD1();
    } else {
      Serial.println("[D2] Latch active, toggle ignored");
    }
  }
  if (d2State != lastD2State) {
    Serial.print("[D2] Button state changed: ");
    Serial.println(d2State ? "RELEASED" : "PRESSED");
  }
  lastD2State = d2State;

  // Latch timer logic: after expiry, allow state changes again, but do not auto-revert relay state
  if (latchTimerExpiry > 0 && millis() > latchTimerExpiry) {
    Serial.print("loop: Latch expired at millis=");
    Serial.print(millis());
    Serial.print(", latchTimerExpiry was ");
    Serial.println(latchTimerExpiry);
    latchTimerExpiry = 0;
  }

  if (Serial.available() > 0) {
    int c = Serial.read();
    if (c == 'm' || c == 'M' || c == '?') {
      WifiConfig cfg;
      loadWifiConfig(cfg);
      printMenu(cfg);
    }
  }
}

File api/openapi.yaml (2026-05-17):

openapi: 3.0.3
info:
  title: ESP8266 D1 HTTP Control API
  version: 1.0.0
  description: |
    REST API for controlling the D1 (GPIO5) relay pin on an ESP8266 NodeMCU.
    Supports ON/OFF/TOGGLE control, latch timer, status queries, and device reset.
    
    **Access Methods:**
    - mDNS (preferred): `http://saturnpsu.local/api/v1/...`
    - By IP: `http://192.168.1.106/api/v1/...`
    
    **Latch Behavior:**
    After a successful control operation, a "latch" period begins during which further
    state changes are blocked (HTTP 423). Latch period is clamped to [1, 3600] seconds.
    After latch expires, the relay remains in its set state (no auto-revert).

servers:
  - url: http://{hostname}.local
    description: mDNS access (auto-discovery, preferred)
    variables:
      hostname:
        default: saturnpsu
  - url: http://{ip}
    description: Static IP access
    variables:
      ip:
        default: '192.168.1.106'

paths:
  /api/v1/status:
    get:
      summary: Get current relay status and latch info
      tags: [Status]
      responses:
        '200':
          description: Current device status
          content:
            application/json:
              schema:
                type: object
                properties:
                  relay_status:
                    type: string
                    enum: [ON, OFF]
                  latch:
                    type: integer
                    minimum: 1
                    maximum: 3600
                  latch_timer_active:
                    type: boolean
                  latch_timer_expiry:
                    type: integer
                  millis:
                    type: integer
              example:
                relay_status: 'ON'
                latch: 5
                latch_timer_active: false
                latch_timer_expiry: 0
                millis: 125432

  /api/v1/on:
    post:
      summary: Set D1 HIGH (turn relay ON)
      tags: [Control]
      responses:
        '200':
          description: Relay ON, latch timer started
          content:
            application/json:
              schema:
                type: object
                properties:
                  relay_status:
                    type: string
                    enum: [ON, OFF]
                  latch:
                    type: integer
                  latch_timer_active:
                    type: boolean
                  latch_timer_expiry:
                    type: integer
                  millis:
                    type: integer
        '423':
          description: Latch active (state change blocked)
          content:
            application/json:
              schema:
                type: object
                properties:
                  error:
                    type: string
                example: {error: 'Latch active'}

  /api/v1/off:
    post:
      summary: Set D1 LOW (turn relay OFF)
      tags: [Control]
      responses:
        '200':
          description: Relay OFF, latch timer started
          content:
            application/json:
              schema:
                type: object
                properties:
                  relay_status:
                    type: string
                  latch:
                    type: integer
                  latch_timer_active:
                    type: boolean
                  latch_timer_expiry:
                    type: integer
                  millis:
                    type: integer
        '423':
          description: Latch active (state change blocked)
          content:
            application/json:
              schema:
                type: object
              example: {error: 'Latch active'}

  /api/v1/toggle:
    post:
      summary: Toggle D1 state (ON→OFF or OFF→ON)
      tags: [Control]
      responses:
        '200':
          description: Relay toggled, new state returned
          content:
            application/json:
              schema:
                type: object
                properties:
                  relay_status:
                    type: string
                  latch:
                    type: integer
                  latch_timer_active:
                    type: boolean
                  latch_timer_expiry:
                    type: integer
                  millis:
                    type: integer
        '423':
          description: Latch active (state change blocked)
          content:
            application/json:
              schema:
                type: object
              example: {error: 'Latch active'}
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

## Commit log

2026-02-15 Add Dockerfile and automated testing documentation
    - Introduced Dockerfile for running Robot Framework API tests.
    - Updated README.md to include automated testing instructions.
    - Added test campaign documentation for comprehensive testing guidelines.
    - Created scripts for Robot Framework tests and usage instructions.
    - Added screenshots documentation for project UI.
2026-02-15 Enhance D1 control firmware with latch timer functionality and API endpoints
2026-02-15 Refactor index.html to inline styles, enhance button color management, and add footer with GitHub link
2026-02-15 Add latch state check to API endpoints to prevent actions during active latch
    [main.cpp]
2026-02-15 Add initial test suite for D1 UI with button state checks and latch input validation
2026-02-15 Add script to run Robot Framework tests in Docker and generate CTRF report
2026-02-15 Refactor Dockerfile to support Robot Framework API and UI tests with Chrome
2026-02-15 Clamp latch period input to valid range (0-3600 seconds)
2026-02-15 Enforce latch period constraints: clamp to valid range [1, 3600] and update tests accordingly
2026-02-15 Add polling test case for D1 state changes in UI
2026-02-15 Improve latch timer logic to clear latch and revert D1 immediately after expiry; add optional reset endpoint for testing
    [main.cpp]
2026-02-16 Add wait loop for latch release in POST Toggle test case
2026-02-16 Refactor API endpoints to include versioning and update documentation; enhance UI button styles and latch functionality
2026-02-16 Refactor latch functionality: update SRS documentation, improve latch timer logic, and enhance test cases for state changes during latch period
2026-02-16 Enhance JSON status response to include latch timer active state and adjust latch timer logic on OFF command
2026-02-16 Reduce sleep duration in latch lockout test case for improved efficiency
2026-02-16 Add KiCad lock and autosave files to .gitignore
2026-02-16 Add selenium to Robot Framework installation in Dockerfile
2026-02-16 Enhance button state management in UI and update SRS documentation for D1 control
2026-02-16 Remove obsolete KiCAD files and import guide for ESP8266 Relay Control project
    [ESP8266_Relay_Control.kicad_pcb, ESP8266_Relay_Control.kicad_sch]
2026-02-17 Enhance API request logging and fix latch expiry handling in control functions
    [main.cpp]
2026-02-17 Add HTML schematic for ESP8266 Relay Control Circuit with detailed component list and usage notes
2026-02-22 Add D2 button handling to toggle D1 state and respect latch logic
2026-02-22 Remove refresh button and update latch input handling in UI
2026-02-22 Remove HTML schematic for ESP8266 Relay Control Circuit
2026-02-22 Add complete HTML schematic for ESP8266 Relay Control System with detailed features and component descriptions
2026-02-22 Add final complete schematic for hardware design
2026-02-23 Remove obsolete README and schematic files from documentation
2026-02-23 Update SRS.md to refine UI button behavior and add D2 push button functionality
2026-02-23 Update test campaign documentation to include D2 push button functionality and refine UI element descriptions
2026-02-23 Implement latch management functions and enhance API for relay control
2026-02-23 Add push button component and wiring instructions for D2 (GPIO4) user input
2026-02-23 Enhance README with detailed D2 push button functionality and UI updates
2026-02-23 Set default WiFi transmit power and apply it during setup
2026-02-23 Remove device back view image from README and adjust formatting
2026-02-27 Refactor API to use 'relay_status' instead of 'd1' for improved clarity and consistency in status responses
2026-05-17 Implement mDNS support for network discovery and update documentation
    - Added mDNS functionality to allow device access via hostname (e.g., saturnpsu.local).
    - Updated README with mDNS access instructions and requirements.
    - Enhanced SRS with network requirements for mDNS.
    - Modified test campaign to include mDNS connectivity tests.
    - Updated test scripts to verify API responses via hostname and IP.
